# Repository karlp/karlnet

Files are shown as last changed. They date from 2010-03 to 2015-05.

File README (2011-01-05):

Hi! This is the karlnet source tree.
karlnet consists of nodes, which are (normally) battery powered sensor devices, transmitting data at some
interval back to a base station.  The base station handles decoding the binary wire formats, and posts all
the data onto a stomp message bus topic. (the base station is a data producer)  Then any consumer that
wishes, simply subscribes to the topic, and receives all data from the network, from the minute the
connect.

common - headers and things for packet definitions, etc
producers - software that can produce data to stick into karlnet, (xbee receiver)
consumers - software that makes use of karlnet data (rrd, webpages, etc)
nodes - firmware that runs on the wireless nodes, and the cad files for each node
eagle - shared files for eagle cad (part libraries)
experiments - uncategorized, or incomplete projects.

python dependencies:
 * Stompy: http://packages.python.org/stompy/
 * python-usb v1.x (you'll have to uninstall 0.4.x, or fiddle with sys.path)
 * python-jsonpickle

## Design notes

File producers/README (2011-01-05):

karlnet data producers

 Producers all push jsonpickle'd "human packets" onto the stomp message bus.

 Human packets are defined in ../common/kpacket.py, but basically contain a node id, a timestamp, and a
set of sensor readings. (with type and units) The producer should also take care of any signal conditioning necessary to
turn the raw sensor readings into humanly useful readings.

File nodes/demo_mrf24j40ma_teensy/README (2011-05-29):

This project demonstrates how to use Microchip's mrf24j40ma 802.15.4 module using my lib_mrf24j code.
The demo is based on PJRC's teensy 2.0 board.

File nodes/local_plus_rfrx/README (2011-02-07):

A firmware designed to both receive karlnet packets over the wireless, as well as report from local
sensors

Initially, targetted at teensy + xbee

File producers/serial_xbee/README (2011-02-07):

Code for dealing with serial streams to and from xbees.

justwatchserial.py - watches for xbee rx 16bit addressing frames on a serial port, decodes them
and posts all messages to the bus
injector.py - creates xbee tx 16 bit address frames, and sends them out via a serially connected
xbee.

An upstart script is included to get this started, and keep it started. 

Requirements:
  * serial port with xbee attached, or xbee compatible emulator
  * stomp broker active. (activemq or similar) (if you want to run in live mode)

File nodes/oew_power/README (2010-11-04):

This node monitors power usage, following the design from http://openenergymonitor.org/emon/node/56

TODO
* add LCD output
* refactor to run on various platforms, namely my dresden mega128rf boards

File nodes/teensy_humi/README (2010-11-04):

basically identical to temphumi, just for a teensy board (atmega32u4) instead of a mega328p.

The code is virtually identical, and it should be merged into that node.

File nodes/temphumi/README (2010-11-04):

nodes that measure temperature and humidity, via a HCH-1000 capacitive sensor, 
connected to a 555 to cause a variable frequency.

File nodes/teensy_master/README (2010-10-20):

For a teensy, with an xbee, to be a listener via usb, rather than via an xbee directly to an FTDI cable.

Right now, it just receives, it should be able to take local measurements too, and interleave them in the
datastream.

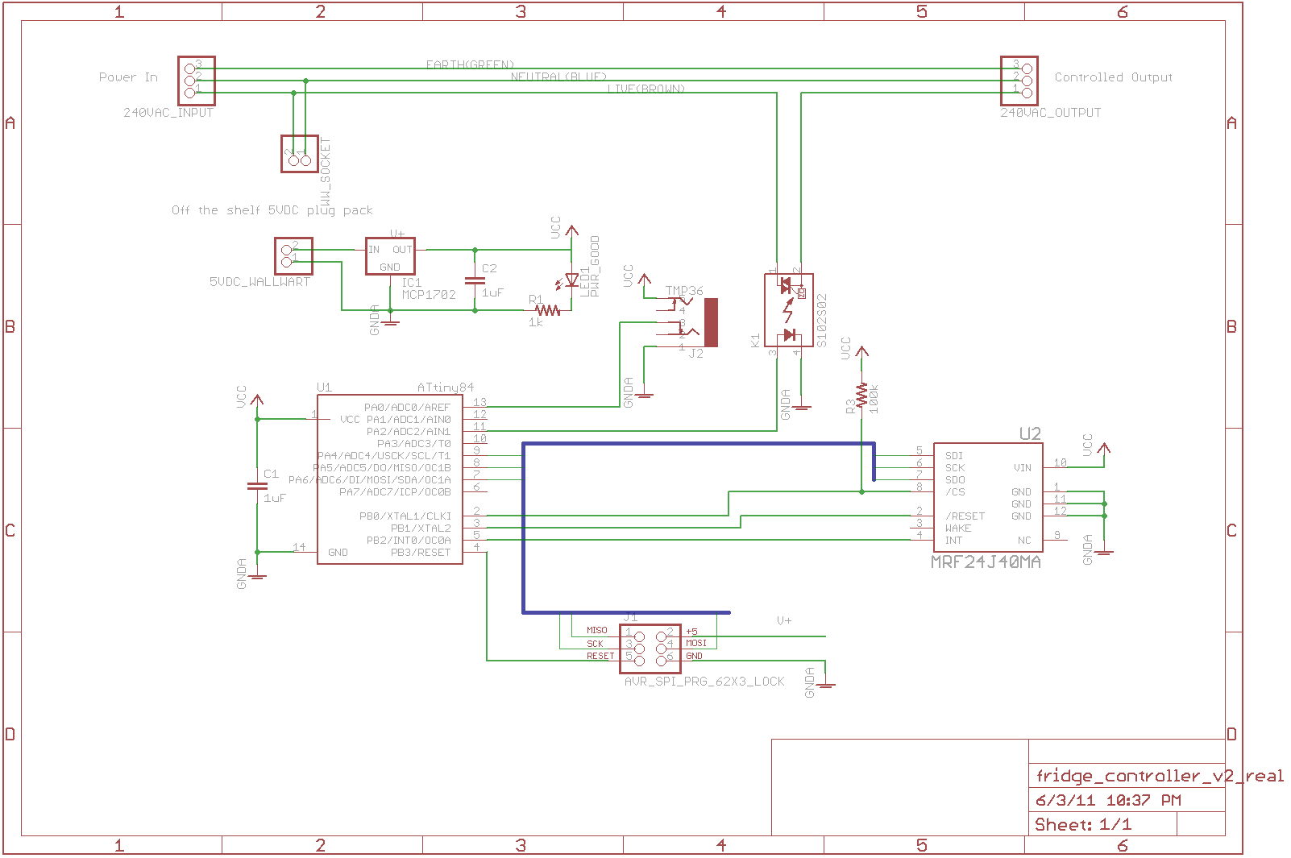
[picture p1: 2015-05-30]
nodes/fridge_controller/fridge_controller_schematic_v2real.png

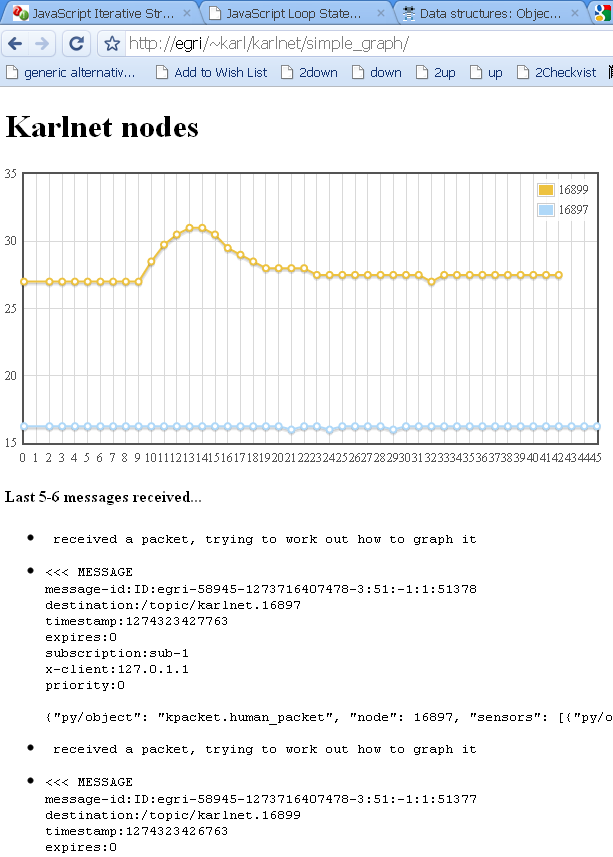
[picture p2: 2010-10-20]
consumers/web/simple_graph/screenshot-rough.png

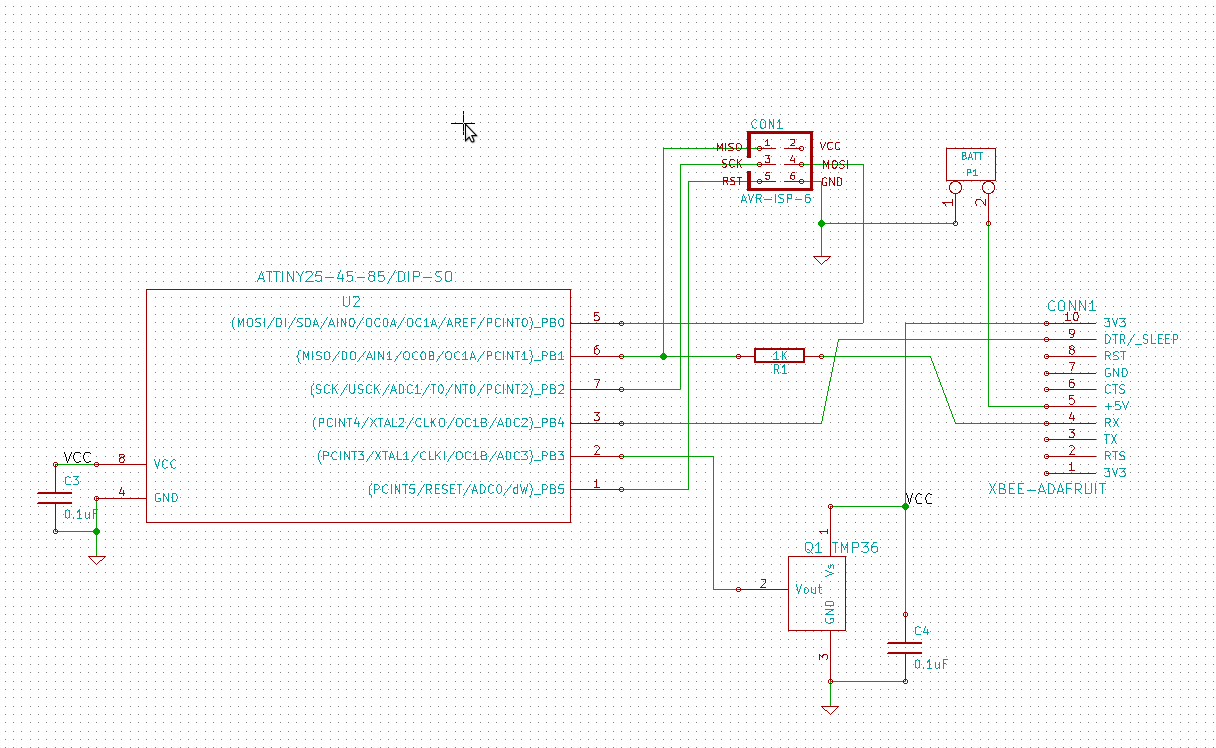
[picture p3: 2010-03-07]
nodes/temphumi/board/tinytemp-3v3.png

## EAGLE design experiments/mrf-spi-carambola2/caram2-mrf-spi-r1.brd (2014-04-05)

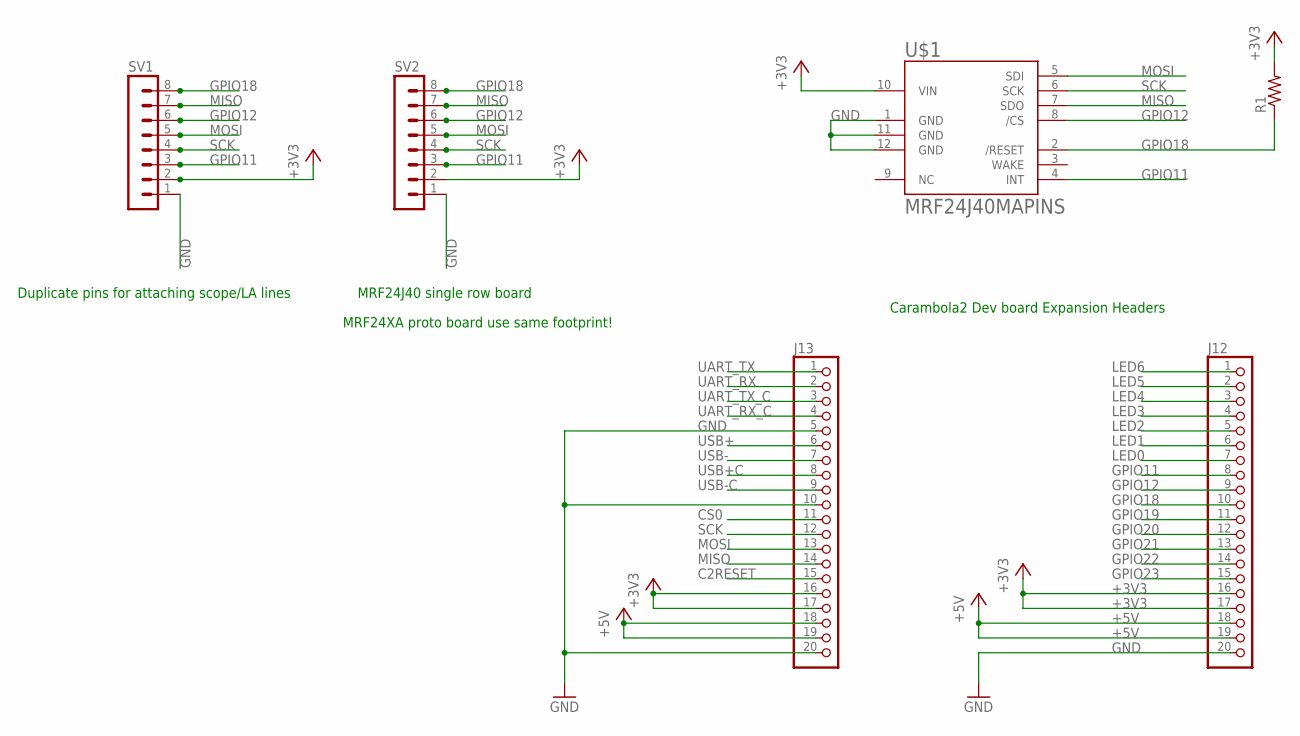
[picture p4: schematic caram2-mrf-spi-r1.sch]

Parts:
J12, J13: PINHD-1X20; 1X20
R1: R-US_R0805; R0805
SV1, SV2: MA08-1
U$1: MRF24J40MAPINS; MRF24J40MA

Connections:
+3V3: J12.16, J12.17, J13.16, J13.17, R1.2, SV1.2, SV2.2, U$1.10 (VIN)
+5V: J12.18, J12.19, J13.18, J13.19
C2RESET: J13.15
CS0: J13.11
GND: J12.20, J13.5, J13.10, J13.20, SV1.1, SV2.1, U$1.1 (GND), U$1.11 (GND), U$1.12 (GND)
GPIO11: J12.8, SV1.3, SV2.3, U$1.4 (INT)
GPIO12: J12.9, SV1.6, SV2.6, U$1.8 (/CS)
GPIO18: J12.10, R1.1, SV1.8, SV2.8, U$1.2 (/RESET)
GPIO19: J12.11
GPIO20: J12.12
GPIO21: J12.13
GPIO22: J12.14
GPIO23: J12.15
LED0: J12.7
LED1: J12.6
LED2: J12.5
LED3: J12.4
LED4: J12.3
LED5: J12.2
LED6: J12.1
MISO: J13.14, SV1.7, SV2.7, U$1.7 (SDO)
MOSI: J13.13, SV1.5, SV2.5, U$1.5 (SDI)
SCK: J13.12, SV1.4, SV2.4, U$1.6 (SCK)
UART_RX: J13.2
UART_RX_C: J13.4
UART_TX: J13.1
UART_TX_C: J13.3
USB+: J13.6
USB+C: J13.8
USB-: J13.7
USB-C: J13.9

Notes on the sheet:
MRF24J40 single row board
MRF24XA proto board use same footprint!
Carambola2 Dev board Expansion Headers
Duplicate pins for attaching scope/LA lines

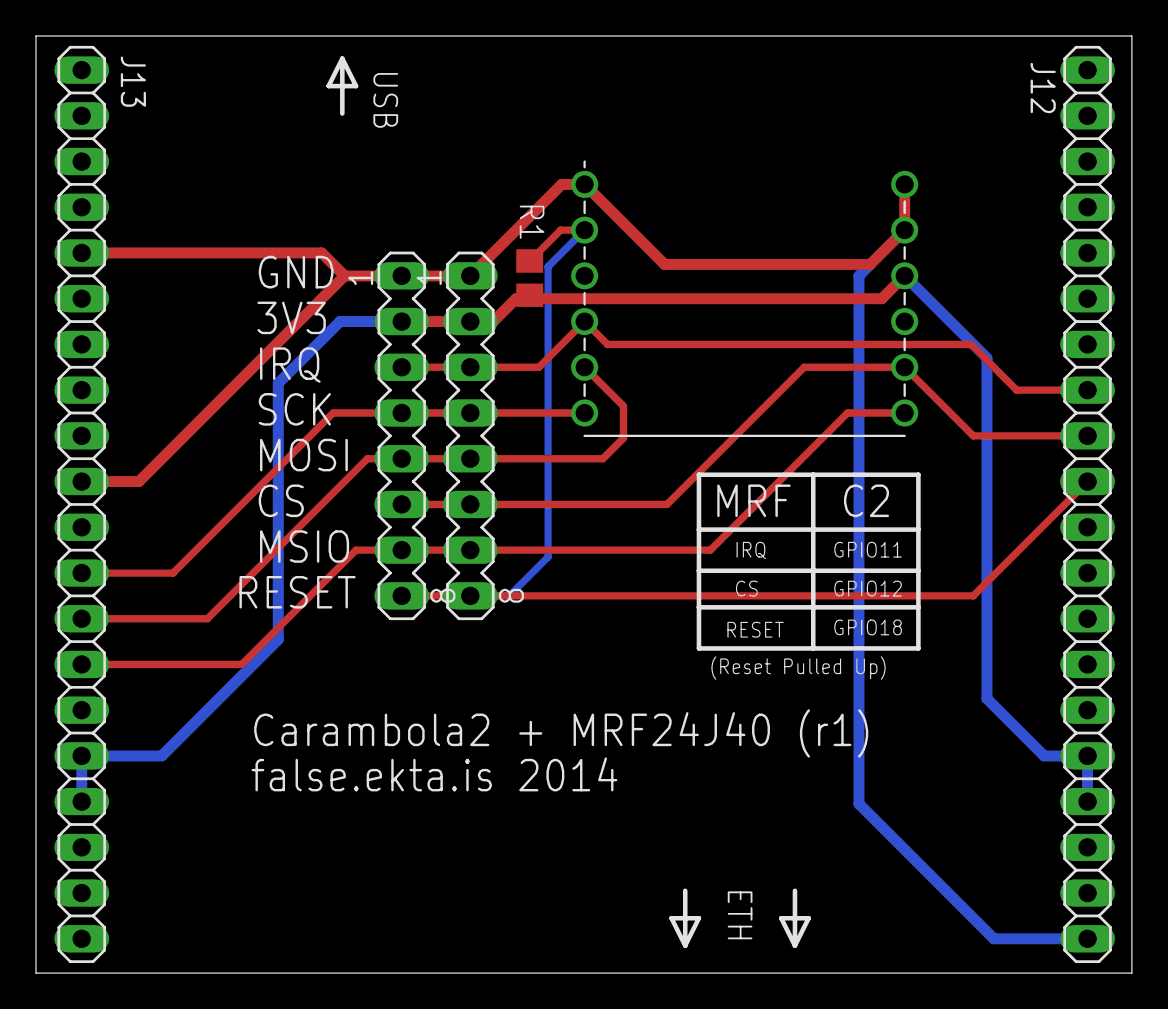
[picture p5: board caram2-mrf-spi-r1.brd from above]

Board: 2 copper layers, 60.9 x 52.1 mm, 6 parts (0 on the bottom side), 9 nets.

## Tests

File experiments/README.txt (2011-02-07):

1. Name: Karl Palsson

2. Company: n/a

3. Billing address: 

Karl Palsson
Hverfisgata 104c
Reykjavik, 101
Iceland

4. Shipping address: 

same as billing

5. Shipping option: airmail

6. Order: 
    1 DSS panel, panelisation image attached as:  olimex-panelisation-20110107.png

7. For all orders from Europe Union: n/a

8. Payment option: Visa

9. De-panelization with smooth or rough borders (read our FAQ for panelization
to learn what does this means)
   Smooth.  I believe my measurements are correct, and there's room for this.

10. Notes: 

    dresdonbo_v02 uses 0.6mm drills, to make sure that the pad/drill spacing meets your
design rules.

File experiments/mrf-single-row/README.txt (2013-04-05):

Designed to turn a mrf24j40 dip 12 module into a sip 8.
Helps on crowded breadboards when used with stm32 discovery boards.

(Wakeup pin is left off, this is just to help get things up and running, not a lasting permnent
design)

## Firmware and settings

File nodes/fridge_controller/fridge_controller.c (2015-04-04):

// Karl Palsson, 2011
// 
// Keep netbeans happy
/*
#ifndef __AVR_ATmega32U4__
#define __AVR_ATmega32U4__
#endif
*/

#include <stdio.h>
#include <stdlib.h>
#include <string.h>
#include <avr/io.h> 
#include <avr/pgmspace.h>
#include <avr/eeprom.h>
#include <avr/power.h>
#include <avr/interrupt.h>
#include <util/delay.h>

#include "lib_mrf24j.h"
#include "karlnet.h"

#define TINY84_HARDWARE
#ifndef TINY84_HARDWARE
#include "pjrc/usb_debug_only.h"
#else
#define printf(x,...)
#endif
#define TICKS_PER_500MS 15625

#if defined(TINY84_HARDWARE)
// USCK and DO pins are output
#define SPI_DDR DDRA
#define SPI_MOSI PINA5
#define SPI_SCLK PINA4
#define RELAY_PORT PORTA
#define RELAY_DDR DDRA
#define RELAY_PIN PINA2
#define MRF_DDR (DDRB)
#define MRF_PORT (PORTB)
#define MRF_PIN_RESET   (PINB1)
#define MRF_PIN_CS      (PINB0)
#define MRF_PIN_INT     (PINB2)
static inline void mrf_enable_interrupts(void) {
    GIMSK |= _BV(INT0);
}
static inline void mrf_disable_interrupts(void) {
    GIMSK &= ~(_BV(INT0));
}

#else
// USCK and DO pins are output
#define SPI_DDR     DDRB
#define SPI_MISO        PINB3
#define SPI_MOSI        PINB2
#define SPI_SCLK        PINB1

#define RELAY_PORT PORTD
#define RELAY_DDR DDRD
#define RELAY_PIN PIND6


#define MRF_DDR DDRB
#define MRF_PORT PORTB
#define MRF_PIN_RESET PINB4
#define MRF_PIN_CS PINB0  // This is also /SS

static inline void mrf_disable_interrupts(void) {
    EIMSK &= ~(_BV(INT0));
}
static inline void mrf_enable_interrupts(void) {
    EIMSK |= _BV(INT0);
}

#endif


#define RELAY_ENABLE (RELAY_DDR |= (1<<RELAY_PIN))
#define RELAY_OFF (RELAY_PORT &= ~(1<<RELAY_PIN))
#define RELAY_ON  (RELAY_PORT |= (1<<RELAY_PIN))



typedef struct _config {
    uint16_t threshold_value;
    uint16_t min_on_time;
    uint16_t min_off_time;
    uint16_t interval_report;
    uint16_t rf_panid;
    uint16_t rf_ourid;
    uint16_t rf_collector;
} configt;

configt config_eeprom EEMEM = {
    .threshold_value = 3,
    .min_off_time = 150,  // about 5 minutes
    .min_on_time = 150,  // about 5 minutes
    .interval_report = 5,
    .rf_panid = 0xcafe,
    .rf_ourid = 0x6002,
    .rf_collector = 0x0001  // teensy receiver station
};

configt config;
uint32_t flags;
// interval_report 1 ==> 2 secs
// interval report 4 ==> 8 secs


// http://www.mail-archive.com/avr-gcc-list@nongnu.org/msg03104.html
static inline uint32_t bswap_32_inline(uint32_t x)
{
        union {
                uint32_t x;
                struct {
                        uint8_t a;
                        uint8_t b;
                        uint8_t c;
                        uint8_t d;
                } s;
        } in, out;
        in.x = x;
        out.s.a = in.s.d;
        out.s.b = in.s.c;
        out.s.c = in.s.b;
        out.s.d = in.s.a;
        return out.x;
}


void init_adc(void) {
    // 1.1V aref, adc0.
    ADMUX = (1<<REFS1);
    ADCSRA |= (1<<ADEN);
}

/**
 * Set up a 500ms per tick timer, using Timer 1
 */
void init_slow_timer(void) {
    // 8mhz internal oscillator / 1024 ==> 7812hz
    // plus clear timer on compare match.
    OCR1A = TICKS_PER_500MS;
    TCCR1B = (1<<WGM12) | (1<<CS12) | (1<<CS10);
    //TCNT1 = 0;
    TIMSK1 = (1<<OCIE1A);
}

uint16_t adc_read(void)
{
    ADCSRA |= (1<<ADSC);               // begin the conversion
    while (ADCSRA & (1<<ADSC)) ;   // wait for the conversion to complete
    unsigned char lsb = ADCL;                              // read the LSB first
    return (ADCH << 8) | lsb;          // read the MSB and return 10 bit result
}

float convert_raw(uint16_t raw) {
    //int32_t milliVolts = ((uint32_t) raw) / 1024 * 1100;
    int32_t milliVolts = ((uint32_t) raw) * 1100;
    milliVolts /= 1024;
    float lessOffset = (float)(milliVolts - 750) / 10.0;
    float tempC = 25 + lessOffset;
    return tempC;
}

static void init_spi(void) {
#if defined (SPCR)
    /* Enable SPI, Master, set clock rate fck/4 */
    SPCR = (1 << SPE) | (1 << MSTR);
#endif
    SPI_DDR |= (_BV(SPI_MOSI) | _BV(SPI_SCLK));
}

#ifndef TINY84_HARDWARE
static int uart_putchar(char c, FILE* stream) {
    return usb_debug_putchar(c);
}
static FILE mystdout = {0};
#endif

void init(configt *config) {
#ifndef TINY84_HARDWARE
    clock_prescale_set(clock_div_2); // we run at 3.3v
    fdev_setup_stream(&mystdout, uart_putchar, NULL, _FDEV_SETUP_WRITE);
    stdout = &mystdout;
    usb_init();
#endif

    MRF_DDR |= (1<<MRF_PIN_RESET) | (1<<MRF_PIN_CS);
    init_spi();
    mrf_enable_interrupts();
    RELAY_ENABLE;
    init_adc();
    init_slow_timer();

    eeprom_read_block(config, &config_eeprom, sizeof(configt));

    mrf_reset(&MRF_PORT, MRF_PIN_RESET);
    mrf_init(&MRF_PORT, MRF_PIN_CS);
    mrf_pan_write(config->rf_panid);
    mrf_address16_write(config->rf_ourid);
#ifndef TINY84_HARDWARE
    while (!usb_configured()) {
    }
    _delay_ms(500);
#endif
    printf("We're awake!\n");
}

volatile uint16_t tick_reporting;
volatile uint32_t tick_motor;

#if defined TINY84_HARDWARE
ISR(TIM1_COMPA_vect) {
#else
ISR(TIMER1_COMPA_vect) {
    putchar('!');
#endif
    tick_reporting++;
    tick_motor++;
    // make sure it's working...
}

ISR(INT0_vect) {
    mrf_interrupt_handler();
}

inline uint8_t get_relay_state(void) {
    if (RELAY_PORT & (_BV(RELAY_PIN))) {
        return 1;
    }
    return 0;
}

void handle_rx(mrf_rx_info_t *rxinfo, uint8_t *rbuf) {
    // we can assume it's for us, because we're in non-prom
    // but we still need to decode the headers, before we get to the kpacket...
    // or... be sneaky...
    if (rxinfo->frame_type != MAC_FRAME_TYPE_DATA) {
        printf("Ignorining non data frame\n");
        return;
    }
    uint8_t  i = 0;
    uint16_t dest_pan = 0;
    uint16_t dest_id = 0;
    uint16_t src_id = 0;
    if (rxinfo->dest_addr_mode == MAC_ADDRESS_MODE_16
            && rxinfo->src_addr_mode == MAC_ADDRESS_MODE_16
            && rxinfo->pan_compression) {
        dest_pan = rbuf[i++];
        dest_pan |= rbuf[i++] << 8;
        dest_id = rbuf[i++];
        dest_id |= rbuf[i++] << 8;
        src_id = rbuf[i++];
        src_id |= rbuf[i++] << 8;
#if PAD_DIGI_HEADER
        // TODO Can't move this into the library without doing more decoding in the library...
        i += 2;  // as in the library, module seems to have two useless bytes after headers!
#endif
    }
    if (dest_id != config.rf_ourid) {
        // unexpected, shouldn't ever happen
        printf("ignoring packet actually meant for %x\n", dest_id);
        return;
    }
    if (src_id != config.rf_collector) {
        // Someone else is trying to tell us to do something!
        printf("Ignoring orders from %x\n", src_id);
        return;
    }

    kpacket2 rxkp;
    memcpy(&rxkp, rbuf+i, sizeof(rxkp));
    if (rxkp.header != 'x') {
        printf("Dropping non kpacket\n");
        return;
    }
    uint8_t version = rxkp.versionCount >> 4;
    uint8_t count = rxkp.versionCount & 0x0f;
    printf("\nRX Kpacket(v:%u, count:%u){\n", version, count);
    for (int k = 0; k < count; k++) {
        rxkp.ksensors[k].value = bswap_32_inline(rxkp.ksensors[k].value);
        printf("\tSensor[t:%x(%c), v=%lx]\n", rxkp.ksensors[k].type,
                rxkp.ksensors[k].type, rxkp.ksensors[k].value);
    }
    uint8_t changed = 0;
    if (rxkp.ksensors[0].type == KPS_COMMAND && rxkp.ksensors[1].type == KPS_COMMAND_ARG) {
        switch (rxkp.ksensors[0].value) {
            case KPS_COMMAND_REPORTING_INTERVAL:
                if (config.interval_report != rxkp.ksensors[1].value) {
                    printf("Updating reporting interval from %u to %lu and saving to eeprom\n",
                            config.interval_report, rxkp.ksensors[1].value);
                    config.interval_report = rxkp.ksensors[1].value;
                    changed = 1;
                }
                break;
            case KPS_COMMAND_THRESHOLD_TEMP:
                if (config.threshold_value != rxkp.ksensors[1].value) {
                    printf("Updating reporting temp threshold from %u to %lu and saving to eeprom\n",
                            config.threshold_value, rxkp.ksensors[1].value);
                    config.threshold_value = rxkp.ksensors[1].value;
                    changed = 1;
                }
                break;
            case KPS_COMMAND_MIN_ON_TIME:
                if (config.min_on_time != rxkp.ksensors[1].value) {
                    printf("Updating min on time from %u to %lu and saving to eeprom\n",
                            config.min_on_time, rxkp.ksensors[1].value);
                    config.min_on_time = rxkp.ksensors[1].value;
                    changed = 1;
                }
                break;
            case KPS_COMMAND_MIN_OFF_TIME:
                if (config.min_off_time != rxkp.ksensors[1].value) {
                    printf("Updating min off time from %u to %lu and saving to eeprom\n",
                            config.min_off_time, rxkp.ksensors[1].value);
                    config.min_off_time = rxkp.ksensors[1].value;
                    changed = 1;
                }
                break;
            case KPS_COMMAND_SET_COLLECTOR:
                if (config.rf_collector != rxkp.ksensors[1].value) {
                    printf("Updating rfcollector from %x to %lx and saving to eeprom\n",
                            config.rf_collector, rxkp.ksensors[1].value);
                    config.rf_collector = rxkp.ksensors[1].value;
                    changed = 1;
                }
                break;
        }
    } else {
        printf("No command seen\n");
    }

    if (changed) {
        eeprom_write_block(&config, &config_eeprom, sizeof(configt));
    }

}

int main(void) {
    init(&config);

    kpacket2 packet;
    packet.header = 'x';
    packet.versionCount = VERSION_COUNT(KPP_VERSION_2, 3);

    sei();
    while (1) {

        mrf_check_flags(&handle_rx, NULL);

        // Read temp
        uint32_t currentValue = adc_read();
        currentValue += adc_read();
        currentValue += adc_read();
        currentValue += adc_read();
        currentValue /= 4;
        float temp = convert_raw(currentValue);

        if (tick_reporting >= config.interval_report) {
            printf("config.interval = %u\n", config.interval_report);
            tick_reporting = 0;
            ksensor s1 = {TMP36_VREF11, currentValue};
            ksensor s2 = {KPS_RELAY_STATE, get_relay_state()};
            ksensor s3 = {KPS_SENSOR_TEST, temp * 100};
            packet.ksensors[0] = s1;
            packet.ksensors[1] = s2;
            packet.ksensors[2] = s3;
            printf("txing...\n");
            mrf_send16(config.rf_collector, sizeof(kpacket2), (char*)&packet);
        }

        // now, check the threshold.  If we're above (too hot),
        // we can turn the motor on, but only if it's off, and only if
        // it's been longer than min_off_time since it was last on...
        if (temp > config.threshold_value) {
            if (!get_relay_state()) {
                if (tick_motor >= config.min_off_time) {
                    RELAY_ON;
                    tick_motor = 0;
                }
            } else {
                // motor is already on, do nothing...
            }
        }
        // likewise, if we're too cold, (anywhere below)
        // we want to turn the motor off, but only if it's on already, and
        // only if it's been on longer than min_on_time
        if (temp <= config.threshold_value) {
            if (get_relay_state()) {
                if (tick_motor >= config.min_on_time) {
                    RELAY_OFF;
                    tick_motor = 0;
                }
            } else {
                // motor is already off, do nothing
            }
        }
    }
}

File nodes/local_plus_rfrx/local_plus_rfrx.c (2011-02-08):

/*
             LUFA Library
     Copyright (C) Dean Camera, 2010.

  dean [at] fourwalledcubicle [dot] com
           www.lufa-lib.org


    Based on DualVirtualSerial demo project,
Guts ripped out and replaced with my own,
Karl Palsson, 2010

*/

/*
  Copyright 2010  Dean Camera (dean [at] fourwalledcubicle [dot] com)

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
  The author disclaim all warranties with regard to this
  software, including all implied warranties of merchantability
  and fitness.  In no event shall the author be liable for any
  special, indirect or consequential damages or any damages
  whatsoever resulting from loss of use, data or profits, whether
  in an action of contract, negligence or other tortious action,
  arising out of or in connection with the use or performance of
  this software.
*/

#include "local_plus_rfrx.h"
#include "karlnet.h"
#include "FreqCounter.h"

#define LOCAL_REPORT_FREQUENCY  3

/** LUFA CDC Class driver interface configuration and state information. This structure is
 *  passed to all CDC Class driver functions, so that multiple instances of the same class
 *  within a device can be differentiated from one another. This is for the first CDC interface,
 *  which sends strings to the host for each joystick movement.
 */
USB_ClassInfo_CDC_Device_t VirtualSerial1_CDC_Interface =
	{
		.Config =
			{
				.ControlInterfaceNumber           = 0,

				.DataINEndpointNumber             = CDC1_TX_EPNUM,
				.DataINEndpointSize               = CDC_TXRX_EPSIZE,
				.DataINEndpointDoubleBank         = false,

				.DataOUTEndpointNumber            = CDC1_RX_EPNUM,
				.DataOUTEndpointSize              = CDC_TXRX_EPSIZE,
				.DataOUTEndpointDoubleBank        = false,

				.NotificationEndpointNumber       = CDC1_NOTIFICATION_EPNUM,
				.NotificationEndpointSize         = CDC_NOTIFICATION_EPSIZE,
				.NotificationEndpointDoubleBank   = false,
			},
	};

/** LUFA CDC Class driver interface configuration and state information. This structure is
 *  passed to all CDC Class driver functions, so that multiple instances of the same class
 *  within a device can be differentiated from one another. This is for the second CDC interface,
 *  which echos back all received data from the host.
 */
USB_ClassInfo_CDC_Device_t VirtualSerial2_CDC_Interface =
	{
		.Config =
			{
				.ControlInterfaceNumber           = 2,

				.DataINEndpointNumber             = CDC2_TX_EPNUM,
				.DataINEndpointSize               = CDC_TXRX_EPSIZE,
				.DataINEndpointDoubleBank         = false,

				.DataOUTEndpointNumber            = CDC2_RX_EPNUM,
				.DataOUTEndpointSize              = CDC_TXRX_EPSIZE,
				.DataOUTEndpointDoubleBank        = false,

				.NotificationEndpointNumber       = CDC2_NOTIFICATION_EPNUM,
				.NotificationEndpointSize         = CDC_NOTIFICATION_EPSIZE,
				.NotificationEndpointDoubleBank   = false,
			},
	};

/** Main program entry point. This routine contains the overall program flow, including initial
 *  setup of all components and the main program loop.
 */
static FILE USBSerialStream;
int main(void)
{
	SetupHardware();
        // Make a stream for channel 2, so we can write more debuggy stuff to it...
        CDC_Device_CreateStream(&VirtualSerial2_CDC_Interface, &USBSerialStream);

	sei();

        kpacket2 packet;
        packet.header = 'x';
        packet.versionCount = VERSION_COUNT(1,3);

        char mychar;
        char waitingForFreq = 0;
        uint32_t frq = 0;
        int localReportCounter = 0;

	for (;;)
	{
		/* Discard all received data on both CDC interfaces */
		CDC_Device_ReceiveByte(&VirtualSerial1_CDC_Interface);
		CDC_Device_ReceiveByte(&VirtualSerial2_CDC_Interface);

                // Serial1 listens for rf data from the serially connected xbee
                if (Serial_IsCharReceived()) {
                    do {
                        mychar = Serial_RxByte();
                        CDC_Device_SendByte(&VirtualSerial1_CDC_Interface, mychar);
                    } while (Serial_IsCharReceived());
                } 

                // if appropriate timing wise, also create and send our own local packet
                uint32_t adc = ADC_GetChannelReading(ADC_REFERENCE_INT2560MV | ADC_CHANNEL0);
                uint32_t itemp = ADC_GetChannelReading(ADC_REFERENCE_INT2560MV | ADC_INT_TEMP_SENS);

                // primitive state machine
                if (!waitingForFreq) {
                    FreqCounter__start(1, 1000);            // Start counting with gatetime of 100ms
                    waitingForFreq = 1;
                    frq = 0;
                }
                if (waitingForFreq && f_ready) {
                    frq = f_freq;
                    waitingForFreq = 0;
                }

                if (frq > 0) {
                    // Remember, this sort of raw string will need a special parser,
                    // it won't have any escaping, rf frame type, or node id
                    if (localReportCounter++ > LOCAL_REPORT_FREQUENCY) {
                        localReportCounter = 0;
                        ksensor s1 = {36, adc};
                        ksensor s2 = {'I', itemp};
                        ksensor s3 = {'f', frq};
                        packet.ksensors[0] = s1;
                        packet.ksensors[1] = s2;
                        packet.ksensors[2] = s3;
                        CDC_Device_SendString(&VirtualSerial2_CDC_Interface, (char *)&packet, 2 + 5 * 3);
                    }
                    frq = 0;
                }

		CDC_Device_USBTask(&VirtualSerial1_CDC_Interface);
		CDC_Device_USBTask(&VirtualSerial2_CDC_Interface);
		USB_USBTask();
	}
}

/** Configures the board hardware and chip peripherals for the demo's functionality. */
void SetupHardware(void)
{
	/* Disable watchdog if enabled by bootloader/fuses */
	MCUSR &= ~(1 << WDRF);
	wdt_disable();

	/* Disable clock division */
	clock_prescale_set(clock_div_1);

	/* Hardware Initialization */
        Serial_Init(19200, false);
        ADC_Init(ADC_PRESCALE_128);
	USB_Init();
}


/** Event handler for the library USB Configuration Changed event. */
void EVENT_USB_Device_ConfigurationChanged(void)
{
	CDC_Device_ConfigureEndpoints(&VirtualSerial1_CDC_Interface);
	CDC_Device_ConfigureEndpoints(&VirtualSerial2_CDC_Interface);
}

/** Event handler for the library USB Control Request reception event. */
void EVENT_USB_Device_ControlRequest(void)
{
	CDC_Device_ProcessControlRequest(&VirtualSerial1_CDC_Interface);
	CDC_Device_ProcessControlRequest(&VirtualSerial2_CDC_Interface);
}

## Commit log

2010-03-07 Fixup paths for new tree
    [justwatchserial.py]
2010-03-07 might maybe be possible to reopen these in kicad...
    [board_tinytemp_3v3.sch, board_tinytemp_5v.sch]
2010-03-08 Fix some path importing so that these work when called from outside the present directory too. (Had some problems with restarts via upstart)
    [justwatchserial.py]
2010-03-09 something's not quite right with power saving mode for the adc, probably not leaving enough time for it to wake up.
    using the ADEN bit instead makes for _much_ more stable readings. (Before I was getting 1-2counts of
    noise!)
    Note: the timeconstant for the tmp36 on the current board layout is _really_ slow.
    [tinytemp.c]
2010-03-09 Fixed my noise problems with the ADC and power saving. (It was probably waiting for the bandgap to stabilise, an extended conversion isn't enough to compensate for that) And now, seems to be down to 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
    [tinytemp.c]
2010-03-09 Add a rough teensy based receiver, to try and work around serial port problems on egri.
    Seems to be just busted usb all round. This was working just fine on tera.
    [pjrc_uart.c, trx.c]
2010-03-09 Switching to full powerdown and the watchdog timer brings us down to 170uA. If I went and actually bothered changing the pin sleep mode for the xbee from doze to hibernate we'd save another 40uA or s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
2010-03-11 Set up .gitignore to ignore all the generated assembly, lists, maps and so on.
    Most importantly, put the common files into a common directory, so that new
    nodes don't have to copy code all over the place
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2010-03-12 Strict checksum checking is no longer option. Now it bins your packets if they fail. This should stop some of the truly bogus values I've seen be decoded as "normal"
    [justwatchserial.py, xbee.py]
2010-03-18 Fix a bug where we tried to calculate a checksum on a packet we were already going to discard
    [xbee.py]
2010-03-18 Fix a bug where an unknown sensor tried to get cast to a tuple, and exploded
2010-03-18 Make the karlnet headend software deal with the "modern" variable length sensor reports
2010-03-18 Use power enable and wakeup time to save a bit more power on the adc
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2010-03-24 Allow the xbee api to gracefull handly variable length sensor reports.
    The memory of the rather ugly fixed length array will still bite me one day I'm sure.
    [karlnet.h]
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2010-05-18 I believe we're correcting cr/lf stuff for the whole repository here.
    [uart.c]
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2010-05-21 added "reliability" to the pyhid reader. It can now reliably reconnect across USB plug/unplugs, (on windows at least) but if you reset the device, it never recovers. :( Not sure why that would be.
    Reliability is based on the serial receiver, and eventually these will merge
    towards each other, so that either one can be a source of kpackets.
    Also added logging to the whole lot.
    [pyhid.py]
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2010-10-20 board files for kicad, but I don't remember the state of the design, just cleaning up missing/lost files in git
    [board_temphumi_5v.brd, board_temphumi_5v.sch, board_tinytemp_3v3.sch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]
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2010-10-21 Make the common avr uart code shared, and add a new power reporting node code.
    It's based on the arduino code, but it's currently completely failing at the
    ADC conversions. Back to the datasheet :)
    [power.c, uart.c]
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2010-10-22 Properly decode rf data, frameid was being skipped
    [xbee.py]
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2010-10-25 Fix the voltage reference!
    [power.c]
2010-10-25 Yuck. No idea what was goign wrong with my function, but inlining it all works. Committing this as a working baseline.
    [power.c]
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2010-10-26 Use a function to do the power meter reading.
    This is far far far from what I call a function, but I was having all sorts of problems getting this to work.
    More to come :|
    [power.c]
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2010-11-04 Add the first cut board and schematic for the tiny84 temp/humi monitors
    [tiny84_temp_humi-v0.1-p4.brd, tiny84_temp_humi-v0.1-p4.sch]
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2010-11-04 Typo in decoder, prevented debug.
    I wonder how I let this get past my testing?!
    [pyhid.py]
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2010-11-07 Handle the strange case of updating tinytemp. For some reason, sending a kpacket with nsensors set to 2 caused it to crash. Instead, fully padded the packets, and added support for decoding that
2010-11-07 Update tinytemp firmware to kpacket version 1.
    Pad wire packets out to MAX_SENSORS. For some reason, tinytemp crashed and went
    haywire if I tried to only send two sensors.
    [tinytemp.c]
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2010-11-18 Adding my "final" mcp1623/24 and 1640/B comparison boards.
    These will be used to compare the PFM/PWM vs PWM only modes,
    and whether that has enough of an impact on ADC stability at low loads.
    (also, let's me test out SMT work, on something that will let me power 3.3v
    off 2xAA batteries.
    [ekta_mcp1640_eval_002.brd, ekta_mcp1640_eval_002.sch]
2010-11-24 Add a new draft of a two channel tiny84 based humidity sensor.
    (Still needs review, plus an LED for the xbee transmit)
    [tiny84xbee-humi_dualProbe_v1b.brd, tiny84xbee-humi_dualProbe_v1b.sch]
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2010-11-24 Add an LED for xbee activity, add a jumper to power from the ICSP
    [tiny84xbee-humi_dualProbe_v2b.brd, tiny84xbee-humi_dualProbe_v2b.sch]
2010-11-24 Connect the RX lines to the xbee, just for future flexibility Connect an optional RSSI indicator LED Connect the CTS_ line from the xbee to the last unused attiny pin, just for future flexibility
    [tiny84xbee-humi_dualProbe_v2d.brd, tiny84xbee-humi_dualProbe_v2d.sch]
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2010-12-05 Make the history sample fixed to the two reliable nodes, and fetch data for both of them
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2010-12-11 Add a "breakout" dresden footprint, and a simple board to use it
    [dresden_breakout_v02.brd, dresden_breakout_v02.sch]
2010-12-11 Based on the misensor.com board, with their modified libraries, a simple breakout for the SHT21
    [SHT21-Breakout-v2b.brd, SHT21-Breakout-v2b.sch]
2010-12-11 Seems to be valid, this is what I'm sending to olimex
    [SHT21-Breakout-v2b.bottomcopper.gbr, SHT21-Breakout-v2b.bottommask.gbr, SHT21-Breakout-v2b.bottomsilk.gbr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]
2010-12-11 Gerbers to be sent to olimex
    [ekta_mcp1640_eval_002.bottomcopper.gbr, ekta_mcp1640_eval_002.bottommask.gbr, ekta_mcp1640_eval_002.bottomsilk.gbr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]
2010-12-11 Gerbers that _should_ work for the dresden board. We'll see what they say :)
    [dresden_breakout_v02.bottomcopper.gbr, dresden_breakout_v02.bottommask.gbr, dresden_breakout_v02.bottomsilk.gbr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]
2010-12-11 Straighten the right edge, WTF happened?
    [tiny84xbee-humi_dualProbe_v2d.brd]
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2010-12-29 Fix a problem decoding tx16 frames, was following the wrong packet format
    [xbee.py]
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2011-01-22 Adding the "fixed" board and schematic after learning about eagle's moronic "restring" These are the boards that olimex is actually making. They rejected v02.
    [dresden_breakout_v02b.brd, dresden_breakout_v02b.sch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]
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2011-01-28 Use the handy stream interface on the second CDC pipeline to do debugging while I'm working out the fine details.
    Fix the ADC too, was using the wrong references
    [local_plus_rfrx.c]
2011-02-02 Demo working frequency, adc and internal temp, with dual USB pipelines.
    It doesn't seem particularly stable though. If I connect to /dev/ttyACM1,
    it seems to happily and reliably keep piping out the string formatted data,
    but rx from the xbee, and piping to /dev/ttyACM0 seems to often get bad packets.
    Perhaps we're not reading from the xbee often enough?
    [local_plus_rfrx.c]
2011-02-02 Fix compiler warning about misnamed function prototypes
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2011-02-02 Use the same optparser tricks to avoid having local changes all the time for testing
    [pyhid.py]
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2011-02-07 Fix frequency counting.
    Original code on teensy humi was actually wrong, sizeof(unsigned int) is actually only 16 bits on avrs,
    so what I was using as the "working reference" was actually only the lower 16 bits.
    Likewise, the odd behaviour with version and sensor count is because ordering and packing of bit fields in C is
    implementation dependent, and nothing to ever rely on.
    [injector.py, karlnet.h, local_plus_rfrx.c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]
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2011-02-07 Remove the decimation and oversampling tricks.
    This would need new sensor type codes, to do the decoding properly, and let's just skip that for now.
    [local_plus_rfrx.c]
2011-02-07 Fix syntax error from auto line wrapping in vim :(
    [local_raw.py]
2011-02-08 Add the NTC temp co data for the waterproof probes I have.
    Source: http://www.specsensors.com/rvt.asp?ptype=1004Z
    [ntc.10kz.curve.csv]
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2011-02-10 Doh, need to set the DDR to output!
    Leaving out a call to TX_CONFIG completely killed this. No wonder it didn't
    work :)
    [combo555.c]
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2011-02-17 Demonstrated standalone frequency counting on the ATtiny84
    Most of my problems seemed to be from DIDR0 = 0, which on the other devices
    saves power, but on the tin84, where T1 is shared with ADC0, it simply
    disabled the digital input, so it never ever, ever counted anything.
    [rawfreq.c]
2011-02-17 Replace busy wait with watchdog timer sleep for 4 seconds.
    The busy wait while the frequency counter is gating is still a major
    power hog, drawing ~3mA for a whole second. This will need to be addressed :)
    [combo555.c]
2011-02-17 Address some of the problems with the v2d PCB, (not all fixes yet)
    [tiny84xbee-humi_dualProbe_v2e.brd, tiny84xbee-humi_dualProbe_v2e.sch]
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2011-02-17 Fix log file path to not collide with the other pipeline receiver
    [local_raw.py]
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2011-02-20 MRF24j startup, can now at least read the short control regs
    [mrf24j.c]
2011-02-20 Add short_read and long read and write, and a lot of datasheet info for bootstrapping
    [mrf24j.c]
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2011-02-20 Dump rxfifo data whenever a packet is received.
    This works, in that it recognises each packet received, but the rxfifo data doesn't seem to match
    what I'm sending.
    [mrf24j.c]
2011-02-20 Was doing something wrong interpreting the datasheet earlier. This is not "correct" but it shows the expected radio data for each packet.
    Note: if you don't read the rxfifo, you won't get any more interrupts for rx. weird, and
    seemingly against the datasheet
    [mrf24j.c]
2011-02-25 Update library and board with some lessons from the first dual probe board.
    3.5mm headphone socket now on the right side of board.
    3.5mm headphone socket now has bigger (hopefully big enough) holes
    new dresden footprints with bigger holes (hopefully big enough)
    fixed most of the todos in the dualprobe, but won't actually get this made.
    [tiny84xbee-humi_dualProbe_v3b.brd, tiny84xbee-humi_dualProbe_v3b.sch]
2011-02-25 Fix problems with the initial dresden breakout board.
    (pins mostly too small, board too wide to fit on a breadboard)
    [dresden_breakout_v03c.brd, dresden_breakout_v03c.sch]
2011-02-27 Tx demo.
    header length calculations seems to be wrong, "data" received by the xbees seems to miss the first two bytes,
    but still passes FCS checks and so on.
    [mrf24j.c]
2011-02-28 Add a simple tx library routine.
    Supports 16 bit addressing only, no acks, and only to the local PAN.
    About the fudge factor:
    Even though the mrf24j40 datasheet and the 802.15.4 standard seem to agree, my
    xbee receivers never ever received the first two bytes of data, but all the
    checksums were correct. Assuming I had an error in my bit field calculation
    for the variable length of the addressing bytes, I tried the following
    combinations, with verification on the receiver, for a four byte packet,
    p[0,1,2,3]
    * 16bit src, no src pan, 16bit dest, dest pan, pan compression bit set:
    correct src, correct dest, received size 2, p[2,3]
    * 16 bit src, src pan, 16bit dest, dest pan, no pan compress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
    [lib_mrf24j.c, lib_mrf24j.h, mrf24j.c]
2011-02-28 Gerbers sent to dorkbot pdx for pcb fab
    [dresden_breakout_v03c.drills.xln]
2011-02-28 properly update the last good timestamp, to avoid needlessly opening and closing the serial port
    [justwatchserial.py]
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2011-05-10 Add schematic for fridge controller
    [fridge_controller_v1.sch]
2011-05-10 Update schematic to use INT0 for the mrf interrupt, and hook up mrf power.
    [fridge_controller_v1.sch]
2011-05-17 Updated schematics to make wiring easier and schematic easier to read.
    [fridge_controller_v1.sch, fridge_controller_v1b.sch]
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2011-05-19 Fix up bus wiring for SPI signals.
    Still no AC on the schematic.
    [fridge_controller_v1b.sch]
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2011-05-26 Made a new footprint for the dresden module to go can side up.
    Made a new layout using that new footprint.
    [dresden_breakout_v04.brd, dresden_breakout_v04.sch]
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2011-05-29 Add the address of the data collection station to config.
    Average the temp readings a little bit, and use the real temperature, to make the threshold a bit better for switching
    state, rather than a raw bit reading, which would be a prone to the noise of the ADC.
    [fridge_controller.c]
2011-05-29 Fix the teensy mrf24j40 demo again.
    I was passing the DDR instead of the PORT to the mrf_reset parameter, so it was never being properly reset.
    [lib_mrf24j.c, lib_mrf24j.h, mrf24j.c]
2011-05-29 Unsure what's changed. Eagle doesn't do diffs very well :(
    [fridge_controller_v1b.sch]
2011-05-29 Use two static variables to hold the chip select pin info.
    This means you no longer have to edit the library header file for each different board.
    [lib_mrf24j.c, lib_mrf24j.h, mrf24j.c]
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2011-05-29 Decode a lot more of the 802.15.4 headers and put them in the rx info object.
    Note, the variable length decoding for addressing is still left to the client. The demo code has been expanded
    to do basic decoding for the 16bit pan compressed addressing I normally use.
    FCS bytes are no longer counted in the rxbuffer length, because, really, who cares. The hardware has already
    taken care of checking it. If you _want_ the fcs bytes are actually hiding at the end of the rxbuffer, in the
    two bytes after the frame length.
    Now, the "packet data" bytes shown are _only_ payload bytes.
    [lib_mrf24j.c, lib_mrf24j.h, mrf24j.c]
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2012-01-08 Add draft schematics. This board has never been built.
    Schematic should be right, but this is an absurd project really.
    [tinytemp3v3-v01.brd, tinytemp3v3-v01.sch]
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2012-05-14 New parts, improved parts
    Fixed silkscreen on top of pads
    Fixed names
    Added parts
2012-05-14 Proposed board for stm32 based mrf node
    STM32F100, lqfp48
    RHT03 for local humidity and temp
    2 jacks for analog inputs (temp probes)
    mrf24j40ma for comms
    mcp1623/1640 SMPS
    designed for a 2xAA batterholder on the flip side
    [boxcar-v2c.brd, boxcar-v2c.sch]
2012-07-24 Totally new layout targetting C4 devices.
    Only has SPI1, so can't use SPI2. Revised layout to vaour vias
    over through hole parts a) more compact and b) when cut on a milling
    machine, it's easier to put in a via than try and make sure to solder
    both sides of through hole parts.
    Correctly provide power to both jacks and the RHT03 device from the mcu
    itself, instead of leaving them permanently powered.
    Correctly include a wakeup pin to the MRF to allow switching it off when desired.
    Correctly place the bigger capacitor on the VDD3 pin as stated in the
    data sheets.
    Use total of 800k resistance instead of 1.5M for the resistor divider. A note
    in the datasheet talks about problems with stray res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
    [boxcar-v3d.brd, boxcar-v3d.sch]
2012-07-24 Fix clearance warning on channel 1 traces
    [boxcar-v3d.brd]
2012-07-24 Add channel 1/2 labels.
    Fix version text to not look "3 dimension" something or other
    [boxcar-v3d.brd]
2012-07-25 Switch to SMT led
    [boxcar-v3e.brd, boxcar-v3e.sch]
2012-09-22 Start 3f, moved for more space, more to go...
    [boxcar-v3f.brd, boxcar-v3f.sch]
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2012-10-09 Updated boards for v3f
    [boxcar-v3f.brd, boxcar-v3f.sch]
2012-10-09 Get the firmware back to something remotely functional
    While we're working on the DHT reading, with a bodged up PCB, just make firmware that supports that.
    We can fix up the pieces later as it comes together.
    [boxcar.c, syscfg.h]
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2012-10-25 More work on viable version.
    [boxcar-v4a.brd, boxcar-v4a.sch]
2012-10-28 Tidied up and almost final verified v4 board.
    Hope the pinouts are right, looks good on board, not sure about in the library.
    Stupid eagle binary formats and branches.
    [boxcar-v4a.brd, boxcar-v4a.sch]
2012-10-28 Final draft before printing and testing fit.
    [boxcar-v4a.brd, boxcar-v4a.sch]
2012-11-20 Fix stlink header drill size to 1mm
    [boxcar-v4a.brd, boxcar-v4a.sch]
2012-11-21 Fix Kycon STX3120 footprint silk and extra drills
2012-11-21 Fix problems uncovered during drill testing.
    NOTE: no longer going to keep renaming files. Letting git do it's thing
    This is now boxcar v4b
    [boxcar-v4a.brd, boxcar-v4a.sch]
2012-11-21 [boxcar] Rename eagle files to stay consistent.
    All v4 style boards will be in this file.
    [boxcar-v4.brd, boxcar-v4.sch]
2012-11-21 [boxcar] avoid PC13,14,15 and their current limitations
    Moved the debug led to the other side.
    Text that used to be in copper layer also moved to silk, as this board will
    not be milled, but produced properly.
    [boxcar-v4.brd, boxcar-v4.sch]
2012-11-21 [boxcar] straight traces
    Now that labels are in silk, no need to avoid them
    [boxcar-v4.brd]
2012-12-17 [boxcar] final version submitted to OSH for manufacturing
    [boxcar-v4.brd, boxcar-v4.sch]
2013-01-28 [boxcar] Update to latest libopencm3
    And of course, actually use the correct hardware defines!
    (yes, these should have gone in separate commits)
    [boxcar.c, syscfg.h]
2013-01-28 [boxcar] remove excessive nastylogging
    nastylogging comes from linux, far too big for this project
    [boxcar.c]
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2013-01-29 [boxcar] toggle power if we have a read failure to the RHT
    Helpful to have a reinit
    [boxcar.c]
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2013-02-01 Oops, missing 802.15.4 files!
    Pushed already, can't rebase now!
    [simrf_plat.c]
2013-02-03 Fix plugged in detection.
    Was using the wrong pullups. (Also, fix all compiler warnings)
    [jacks.c, syscfg.h]
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2013-02-14 Replace stomp with mqtt.
    Servers are far easier to manage, client tools are easier to use.
    [justwatchserial.py]
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2013-04-05 [experiments] add mrf-single-row test board
    [mrf-single-row.brd, mrf-single-row.sch]
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2013-06-12 Fix footprint for 50mil jtag
    Totally moronic, put it on a 100mil grid instead of a 50mil grid :(
2014-04-05 Carambola2-mrf24j40 breakout
    Now just to get the software working....
    [caram2-mrf-spi-r1.brd, caram2-mrf-spi-r1.sch]
2015-04-04 remove fake padding for avoiding DIGIMESH headers
    [fridge_controller.c, lib_mrf24j.c]
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2015-05-30 tiny84xbee: switch to mrf24j40: never-made, never finished
    Drafted a version on mrf24j40, but never finished, decided a proper course was
    redoing the whole design from scratch.
    [tiny84xbee-humi_dualProbe_v4.brd, tiny84xbee-humi_dualProbe_v4.sch]
2015-05-30 fridge_controller: include final schematics
    No board file, this was made up on veroboard a long time ago.
    [fridge_controller_v2_real.sch]
2015-05-31 dresden: 9600 baud? what century is this!
    115200 doesn't actually work, might need double speed mode?
    [blinky.c]
